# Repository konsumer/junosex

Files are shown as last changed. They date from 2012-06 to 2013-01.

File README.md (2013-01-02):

# Control Roland Alpha Juno 1, 2, 106 & MKS-50 with MIDI CC, instead of SysEx

All decent MIDI sequencers speak CC, but being able to speak SysEx particular to these synths is harder to come by.  This code, when placed on an ATMEGA8/168/328 will do the conversion for you, and allow your computer/ipad/sequencer to get romantic with your Juno.

There are 2 versions. One is a software implementation, and one is an Arduino-based version. I made several options for putting it together in either form.

## Software Version

I  made a CLI-version, and a GUI version.

### command-line

To install the CLI dependencies, run this, in the software directory:

    npm install

You can get help with:

    ./junosex --help

### GUI

I only tested this on Mac, so that is the only platform I included, but the process should be fairly similar. For Mac, just extract software/JunoSex-mac.zip, and run. For other platforms, you can run `npm install` to build MIDI, put the contents of junosex.nw (make package.json be in root) into a zip file and change the extension to `.nw`, which should make it run if you have the [node-webkit] runtime installed. They also have some info on building a stand-alone app on their site.

The build process is the same as CLI, using the software/junosex.nw directory and the [node-webkit] runtime for your system. I had to use `nw-gyp` to make it build the MIDI library for 32bit (a current limitation of [node-webkit]: Mac requires 32bit versions of everything.) but Mac-peeps should be covered with premade zipfile.

## Hardware Version

The hardware version can be made with an Arduino and a [MIDI shield] or [MIDI breakout], or you can make it on a custom PCB with an ATMEGA chip, or a [cheap-o USB-to-MIDI adapter] and an ATMEGA/Arduino.

The [Arduino MIDI Library] is required. I compiled the code in the Arduino IDE.

### Arduino

The arduino/shield route just requires that you put them together, and run the Arduino code (junosex.ino.) This should take about 5 minutes to complete.

### Custom PCB / ATMEGA

Follow the [schematic] to put it together. I will provide better instructions, later. I used [ArduinoISP] running on a [teensy] to program an [ATMEGA8]. I used a [resonator] to be cheap and lazy (rather than a crystal and 2 capacitors.)

If you want it to run on batteries, use a 9V battery and a [7805 regulator].

I made a full [parts list], for mouser, to build what is listed in the schematic. I just picked parts that are cheap and available. Feel free to choose replacements.

### [cheap-o USB-to-MIDI adapter]

If you are using a [cheap-o USB-to-MIDI adapter], you can open it up, and solder the wires direct to TX/RX, and use the power/ground from USB (inside adapter) to make it all simpler/cheaper.

### Modification

Feel free to modify. This thing is super-simple.

Some ideas:
* put RGB LEDs on PWM pins, for cool light-effects when different control messages are sent
* add knobs to change how CCs are interpreted, or set values directly
* Attach [wireless] to it for cheap, so you can hide your computer/sequencer.

[ATMEGA8]: http://www.mouser.com/ProductDetail/Atmel/ATMEGA8-16PU/?qs=7JStj%2fjQ2SHlSx6QootzDTUTMpkFcVaHHuOB6ZSDMnk%3d
[resonator]: http://www.mouser.com/Search/ProductDetail.aspx?R=HWZT-16.00MDvirtualkey52750000virtualkey815-HWZT-16.00MD
[ArduinoISP]: http://arduino.cc/en/Tutorial/ArduinoISP
[Arduino MIDI Library]: http://arduino.cc/playground/Main/MIDILibrary
[wireless]: http://www.sparkfun.com/products/10532
[teensy]: http://www.pjrc.com/store/teensy.html
[cheap-o USB-to-MIDI adapter]: http://shiftmore.blogspot.com/2010/01/quick-and-dirty-arduino-midi-over-usb.html
[schematic]: https://github.com/konsumer/junosex/raw/master/schematic.png
[7805 regulator]: http://www.mouser.com/ProductDetail/ON-Semiconductor/MC7805CTG/?qs=%252b9%2fcbd0IE0RkDYggsVZtGe3PoqBzrkPO
[parts list]: http://www.mouser.com/ProjectManager/ProjectDetail.aspx?AccessID=fe0a4b4498
[MIDI shield]: https://www.sparkfun.com/products/9595
[MIDI breakout]: https://www.sparkfun.com/products/9598
[node-webkit]: https://github.com/rogerwang/node-webkit

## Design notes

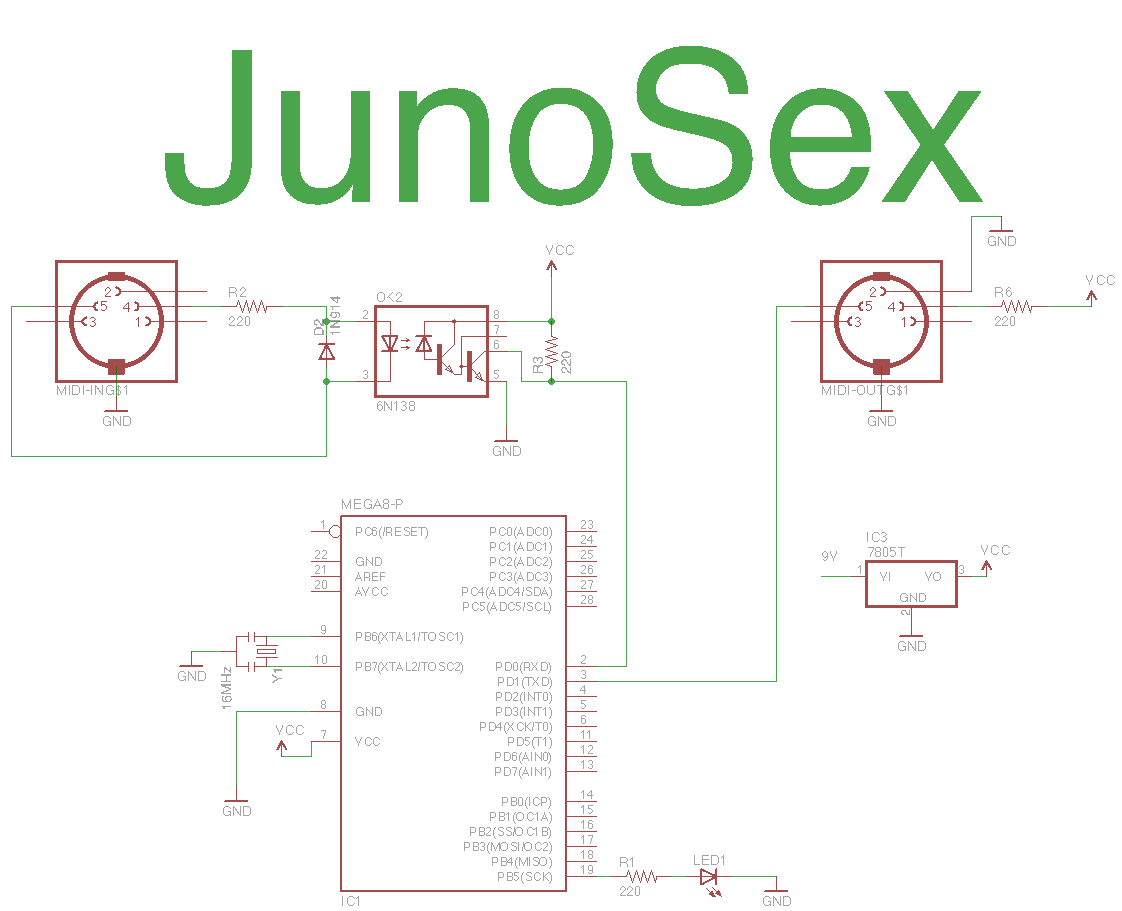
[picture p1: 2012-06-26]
schematic.png

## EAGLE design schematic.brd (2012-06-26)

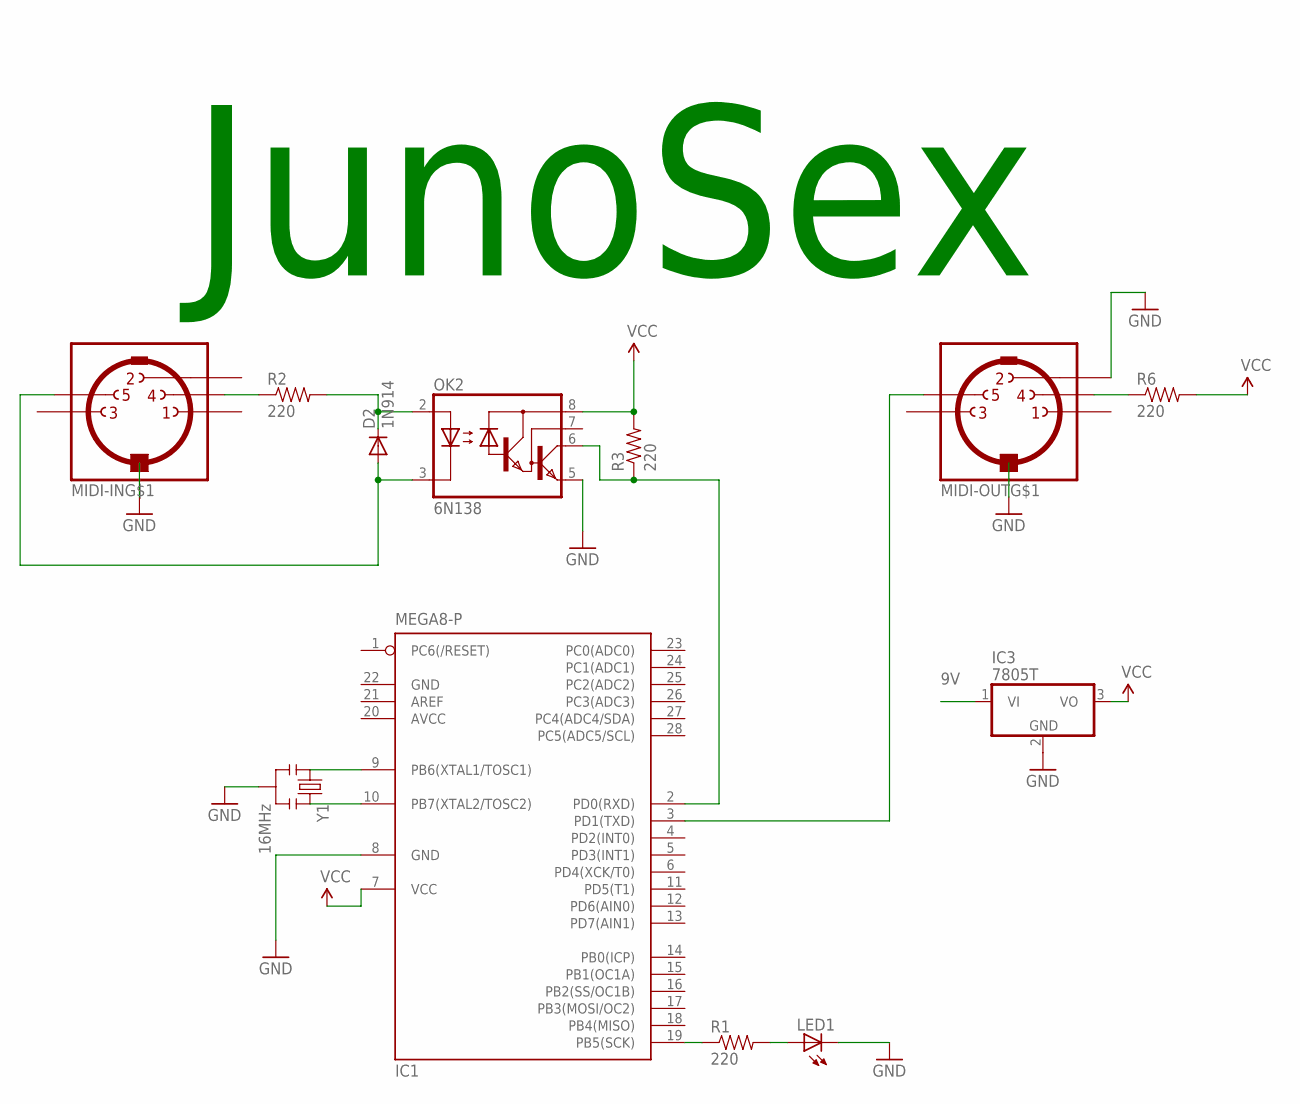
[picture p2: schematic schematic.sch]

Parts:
D2: 1N914; DIODE-1N4148
IC1: MEGA8-P; DIL28-3
IC3: 7805T; TO220H
LED1: LED5MM
MIDI-IN: MIDIJACK; CP-2350
MIDI-OUT: MIDIJACK; CP-2350
OK2: 6N138; DIL08
R1, R2, R3, R6: 220; AXIAL-0.3
Y1: 16MHz; RESONATOR-PTH

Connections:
9V: IC3.1 (VI)
AVCC: IC1.20 (AVCC)
GND: IC1.8 (GND), IC1.22 (GND), IC3.2 (GND), LED1.K (C), MIDI-OUT.2, OK2.5 (GND), Y1.2
unnamed: IC1.9 (PB6(XTAL1/TOSC1)), Y1.1
unnamed: IC1.10 (PB7(XTAL2/TOSC2)), Y1.3
unnamed: MIDI-IN.4, R2.P$1 (1)
unnamed: D2.A, MIDI-IN.5, OK2.3 (C)
unnamed: D2.C, OK2.2 (A), R2.P$2 (2)
unnamed: MIDI-OUT.4, R6.P$1 (1)
unnamed: IC1.2 (PD0(RXD)), OK2.6 (VO), R3.P$1 (1)
unnamed: IC1.3 (PD1(TXD)), MIDI-OUT.5
unnamed: IC1.19 (PB5(SCK)), R1.P$1 (1)
unnamed: LED1.A, R1.P$2 (2)
VCC: IC1.7 (VCC), IC3.3 (VO), OK2.8 (VCC), R3.P$2 (2), R6.P$2 (2)

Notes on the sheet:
JunoSex

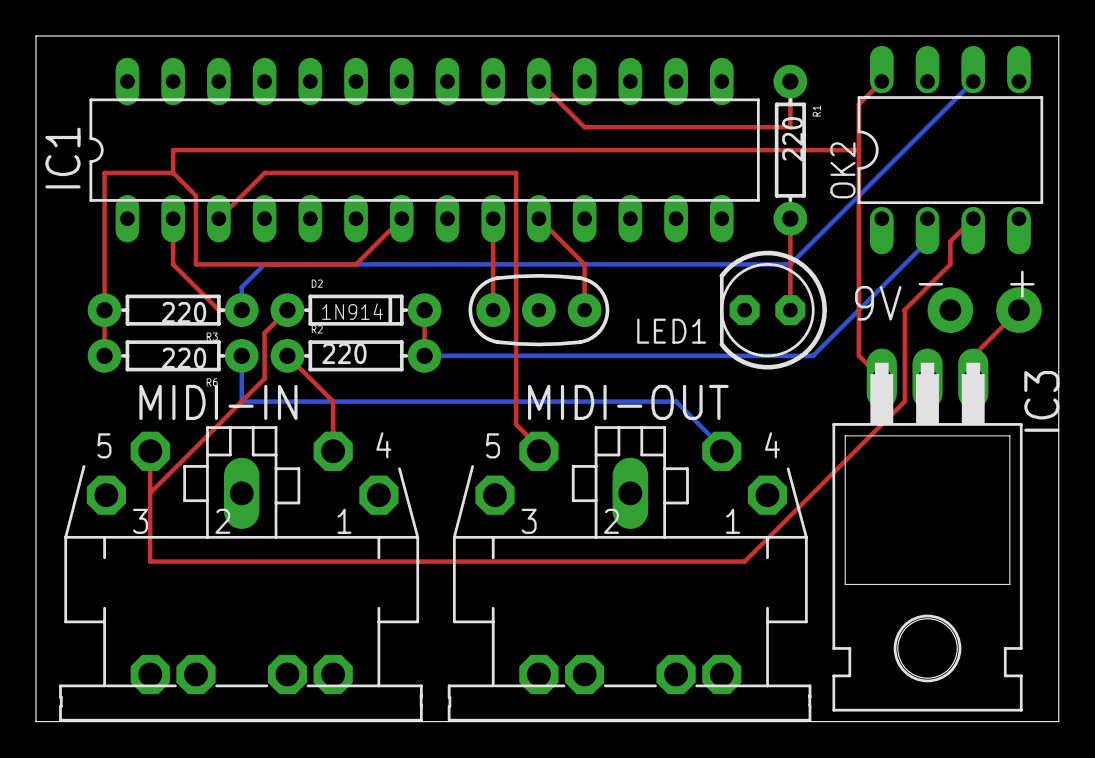
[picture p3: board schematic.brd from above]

Board: 2 copper layers, 56.8 x 38.1 mm, 12 parts (0 on the bottom side), 12 nets.

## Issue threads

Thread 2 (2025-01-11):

Compilation error: 'MIDI' was not declared in this scope

kabrio, 2025-01-11:
When trying to compile the provided Arduino sketch I was getting error:

> Compilation error: 'MIDI' was not declared in this scope

After some research I realised that the following function call was missing from the sketch:

`MIDI_CREATE_DEFAULT_INSTANCE();`

After adding that after `#include <MIDI.h>` the code compiled just fine.

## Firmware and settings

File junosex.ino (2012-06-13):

/*

Adds CC messages to sysex params for Roland Alpha Juno 1, 2, 106 & MKS-50 Control

See here for info about available sysex params:
http://www.vintagesynth.com/roland/sysex.php

Hardware:

ATMEGA8/168/328 chip pins:

2 (RX) -> photocoupler -> midi-in       
3 (TX) -> midi-out
9 & 10 (OSC): 16MHz resonator
19 (D13) - optional status LED

*/

#include <MIDI.h>

// if you have a Roland Juno 106, uncomment this
//#define JUNO106

// param-count
#ifdef JUNO106
  #define PCOUNT 16
#else
  #define PCOUNT 36
#endif

// this is the map of midi controls to Sysex controls.
// key is midi CC#, val is Juno param #
byte control_map[127] = {0xFF};

// this is the list of scale vals for controls that are not 0..7F
// it's just a list of the "high" number
// key is Juno param #, val is top-number in scale
byte val_map[PCOUNT] = {0x7F};

// optional status indicator
#define LED_PIN 13

// generic iterator
byte i = 0;

// value to send to Juno param
byte val = 0;

// scale to use in sysex
float multiplier = 0;

void HandleControlChange (byte channel, byte number, byte value){      
  if (control_map[number] != 0xFF){
    // forward control message to sysex
    digitalWrite(LED_PIN, HIGH);
    
    // scale value to proper range
    multiplier = (val_map[control_map[number]]/127.0);
    val = multiplier * value;
    
    #ifdef JUNO106
      byte msg[5] = {0x41, 0x32, channel-1, control_map[number], val};
    #else
      byte msg[8] = {0x41, 0x36, channel-1, 0x23, 0x20, 0x01, control_map[number], val};
    #endif
    
    MIDI.sendSysEx(sizeof(msg), msg);
    digitalWrite(LED_PIN, LOW);
  }
}

void setup() {
  pinMode(LED_PIN, OUTPUT);

  // setup mappings
  #ifdef JUNO106
  
    // LFO rate
    control_map[0x33] = 0x00;
    val_map[0x00] = 0x7F;
    
    // LFO delay
    control_map[0x31] = 0x01;
    val_map[0x01] = 0x7F;
    
    // DCO LFO modulation level
    control_map[0x21] = 0x02;
    val_map[0x02] = 0x7F;
    
    // DCO PWM modulation level
    control_map[0x25] = 0x03;
    val_map[0x03] = 0x7F;
    
    // Noise level
    control_map[0x20] = 0x04;
    val_map[0x04] = 0x7F;
    
    // VCF cutoff level
    control_map[0x74] = 0x05;
    val_map[0x05] = 0x7F;
    
    // VCF resonance level
    control_map[0x71] = 0x06;
    val_map[0x06] = 0x7F;
    
    // VCF ENV level
    control_map[0x75] = 0x07;
    val_map[0x07] = 0x7F;
    
    // VCF LFO modulation level
    control_map[0x33] = 0x08;
    val_map[0x08] = 0x7F;
    
    // VCF KYBD modulation level
    control_map[0x70] = 0x09;
    val_map[0x09] = 0x7F;
    
    // VCA level
    control_map[0x39] = 0x0a;
    val_map[0x0a] = 0x7F;
    
    // ENV attack rate
    control_map[0x73] = 0x0b;
    val_map[0x0b] = 0x7F;
    
    // ENV decay rate
    control_map[0x80] = 0x0c;
    val_map[0x0c] = 0x7F;
    
    // ENV sustain level
    control_map[0x76] = 0x0d;
    val_map[0x0d] = 0x7F;
    
    // ENV release rate
    control_map[0x72] = 0x0e;
    val_map[0x0e] = 0x7F;
    
    // Sub level
    control_map[0x77] = 0x0f;
    val_map[0x0f] = 0x7F;

  #else
    // DCO Env. Mode (0=Normal, 1=Inverted, 2=Normal-Dynamic, 3=Inv.-Dynamic)
    control_map[0x12] = 0x00;
    val_map[0x00] = 3;

    // VCF Env. Mode (0=Normal, 1=Inverted, 2=Normal-Dynamic, 3=Dynamic)
    control_map[0x13] = 0x01;
    val_map[0x01] = 3;

    // VCA Env. Mode (0=Normal, 1=Gate, 2=Normal-Dynamic, 3=Gate-Dynamic)
    control_map[0x14] = 0x02;
    val_map[0x02] = 3;

    // DCO Wave Pulse (0..3)
    control_map[0x15] = 0x03;
    val_map[0x03] = 3;

    // DCO Wave Saw (0..5)
    control_map[0x16] = 0x04;
    val_map[0x04] = 5;

    // DCO Wave Sub (0..5)
    control_map[0x17] = 0x05;
    val_map[0x05] = 5;

    // DCO Range (0=4', 1=8', 2=16', 3=32')
    control_map[0x18] = 0x06;
    val_map[0x06] = 3;

    // DCO Sub Level (0..3)
    control_map[0x19] = 0x07;
    val_map[0x07] = 3;

    // DCO Noise (0..3)
    control_map[0x20] = 0x08;
    val_map[0x08] = 3;

    // HPF Cutoff (0..3)
    control_map[0x81] = 0x09;
    val_map[0x09] = 3;

    // Chorus Switch (0=Off, 1=On)
    control_map[0x80] = 0x0A;
    val_map[0x0A] = 1;

    // DCO LFO Mod. (0..7F)
    control_map[0x21] = 0x0B;
    val_map[0x0B] = 0x7F;

    // DCO ENV Mod. (0..7F)
    control_map[0x22] = 0x0C;
    val_map[0x0C] = 0x7F;

    // DCO After Mod. (0..7F)
    control_map[0x23] = 0x0D;
    val_map[0x0D] = 0x7F;

    // DCO PWM Depth (0..7F)
    control_map[0x24] = 0x0E;
    val_map[0x0E] = 0x7F;

    // DCO PWM Rate (0..7F) 0 = Pulse Width Manual 1..7F = PW LFO Rate
    control_map[0x25] = 0x0F;
    val_map[0x0F] = 0x7F;

    // VCF Cutoff (0..7F)
    control_map[0x74] = 0x10;
    val_map[0x10] = 0x7F;

    // VCF Resonance (0..7F)
    control_map[0x71] = 0x11;
    val_map[0x11] = 0x7F;

    // VCF LFO Mod. (0..7F)
    control_map[0x26] = 0x12;
    val_map[0x12] = 0x7F;

    // VCF ENV Mod. (0..7F)
    control_map[0x27] = 0x13;
    val_map[0x13] = 0x7F;

    // VCF Key Follow (0..7F)
    control_map[0x28] = 0x14;
    val_map[0x14] = 0x7F;

    // VCF Aftertouch (0..7F)
    control_map[0x29] = 0x15;
    val_map[0x15] = 0x7F;

    // VCA Level (0..7F)
    control_map[0x39] = 0x16;
    val_map[0x16] = 0x7F;

    // VCA Aftertouch (0..7F)
    control_map[0x30] = 0x17;
    val_map[0x17] = 0x7F;

    // LFO Rate (0..7F)
    control_map[0x33] = 0x18;
    val_map[0x18] = 0x7F;

    // LFO Delay (0..7F)
    control_map[0x31] = 0x19;
    val_map[0x19] = 0x7F;

    // ENV T1 (0..7F) Attack Time
    control_map[0x73] = 0x1A;
    val_map[0x1A] = 0x7F;

    // ENV L1 (0..7F) Attack Level
    control_map[0x75] = 0x1B;
    val_map[0x1B] = 0x7F;

    // ENV T2 (0..7F) Break Time
    control_map[0x76] = 0x1C;
    val_map[0x1C] = 0x7F;

    // ENV L2 (0..7F) Break Level
    control_map[0x77] = 0x1D;
    val_map[0x1D] = 0x7F;

    // ENV T3 (0..7F) Decay Time
    control_map[0x80] = 0x1E;
    val_map[0x1E] = 0x7F;

    // ENV L3 (0..7F) Sustain Level
    control_map[0x79] = 0x1F;
    val_map[0x1F] = 0x7F;

    // ENV T4 (0..7F) Release Time
    control_map[0x72] = 0x20;
    val_map[0x20] = 0x7F;

    // ENV Key Follow (0..7F)
    control_map[0x82] = 0x21;
    val_map[0x21] = 0x7F;

    // Chorus Rate (0..7F)
    control_map[0x93] = 0x22;
    val_map[0x22] = 0x7F;

    // Bender Range (0..C)
    control_map[0x6] = 0x23;
    val_map[0x23] = 0xC;
  #endif
  
  // you could also listen on just one channel, if you have a lot of devices chatting CCs on other channels
  MIDI.begin();
  MIDI.setHandleControlChange(HandleControlChange);
  
  // blink LED to say "hello"
  for (i=0; i<4; i++){
    digitalWrite(LED_PIN, HIGH);
    delay(100);
    digitalWrite(LED_PIN, LOW);
    delay(100);
  }
}

void loop() {
  MIDI.read();
}

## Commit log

2012-06-11 fixed symlinks
    [schematic.sch]
2012-06-11 added label to schematic
2012-06-11 updated label of photo coupler to match mine
2012-06-11 updated schematic source, also
    [schematic.sch]
2012-06-13 faster control_map lookup in arduino code, using better optocoupler in schematic
    [schematic.sch]
2012-06-13 added link to schematic image
2012-06-26 better schematic support
    [schematic.brd, schematic.sch]

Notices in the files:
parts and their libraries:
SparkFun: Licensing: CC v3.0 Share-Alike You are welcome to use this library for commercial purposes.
